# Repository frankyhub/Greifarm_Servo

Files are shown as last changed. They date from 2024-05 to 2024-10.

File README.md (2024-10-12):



<div align="center">

|[:skull:ISSUE](https://github.com/frankyhub/Greifarm_Servo/issues?q=is%3Aissue)|[:speech_balloon: Forum /Discussion](https://github.com/frankyhub/Greifarm_Servo/discussions)|[:grey_question:WiKi](https://github.com/frankyhub/Greifarm_Servo/wiki)||
|--|--|--|--|
| | | | |
||<a href="https://github.com/frankyhub/Greifarm_Servo/issues">|<a href="https://github.com/frankyhub/Greifarm_Servo/discussions">|<a href="https://github.com/frankyhub/Greifarm_Servo/releases">|
|| <a href="https://github.com/frankyhub/Greifarm_Servo/pulse" alt="Activity">| <a href="https://github.com/frankyhub/Greifarm_Servo/graphs/traffic">  |<a href="https://github.com/frankyhub?tab=stars"> |
</div>

# Greifarm mit Servo-Motore

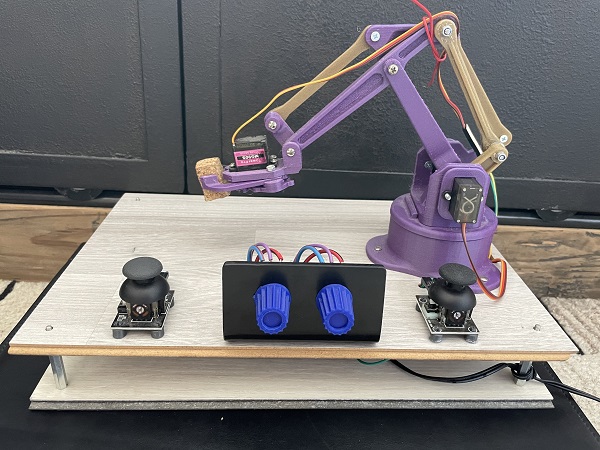
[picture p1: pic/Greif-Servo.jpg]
Bild


---

<div style="position:absolute; left:2cm; ">   
<ol class="breadcrumb" style="border-top: 2px solid black;border-bottom:2px solid black; height: 45px; width: 900px;"> <p align="center"><a href="#oben">nach oben</a></p></ol>
</div>  

---

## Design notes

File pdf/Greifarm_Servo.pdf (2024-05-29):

http://www.instructables.com/id/EEZYbotARM/technology (http://www.instructables.com/tag/type-id/category-technology/) workshop (http://www.instructables.com/tag/type-id/category-workshop/) craft (http://www.instructables.com/tag/type-id/category-craft/) home (http://www.instructables.com/tag/type-id/category-home/) food (http://www.instructables.com/tag/type-id/category-food/) play (http://www.instructables.com/tag/type-id/category-play/) outside (http://www.instructables.com/tag/type-id/category-outside/) costumes (http://www.instructables.com/tag/type-id/category-costumes/)

# EEZYbotARM

by theGHIZmo (http://www.instructables.com/member/theGHIZmo/?utm_source=pdf&utm_campaign=title) on September 29, 2015

Table of Contents

## Intro: EEZYbotARM

This ia a 3DPrinted robot arm.

The design intent was to make something "easy" to build and quite cheap

It uses MG90S small servos for driving the kinematics linkage and a Pololu mini maestro 12 to control the servos (but this is my choice any other methods are valid)

All the pieces are 3DPrinted in ABS but any other material like PLA can be used

3D models in stl format can be downloaded for free at Thingiverse : http://www.thingiverse.com/thing:1015238

video of :

ramp loop test :

https://youtu.be/qovZKW0DxWk

preliminary tests video :

https://www.youtube.com/watch?v=x9C_3WHr1G0

https://www.youtube.com/watch?v=0OFL6MxbPIM

Part list:

n° 17 3D printed parts

n* 3 Tower Pro MG90S servos

n* 1 SG90 servo (gripper) + 1 optional for the loop ramp

n° 7 M4 self locking nuts

n° 15 M4 washers

n° 7 M3 nuts

n° 1 M3 x 30 screw

n° 2 M3 washers

n° 4 M3 x 12 hex screw

n° 2 M3 x 12 TCEI screw

n° 2 M3 x 20 TCEI screw

n° 1 brass pipe 4 x 3 x 22 + n°1 4 x 3 x 26

ELECTRONICS

The Arm can be driven in several different ways : sketches, potentiometers, joystick, WII nunchuck …. after several trials I found very "easy" to use a controller from Pololu: Mini Maestro USB Servo Controller. You can attach up to 6 – 12 – 24 servos depend of the controller type. It is provided with a free configuration and control program for Windows and Linux that give you the power to drive the servo in manual moving slides; in the mean time you are able to set the values of speed and acceleration for any singular item. You can also build sequences of servo movements and run scripts stored in the internal script memory that can be automatically played back without any computer or external microcontroller connected.

here the link of the Pololu servo controller: https://www.pololu.com/product/1352

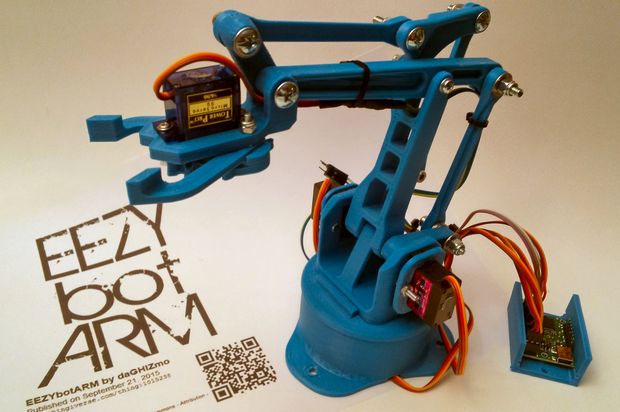
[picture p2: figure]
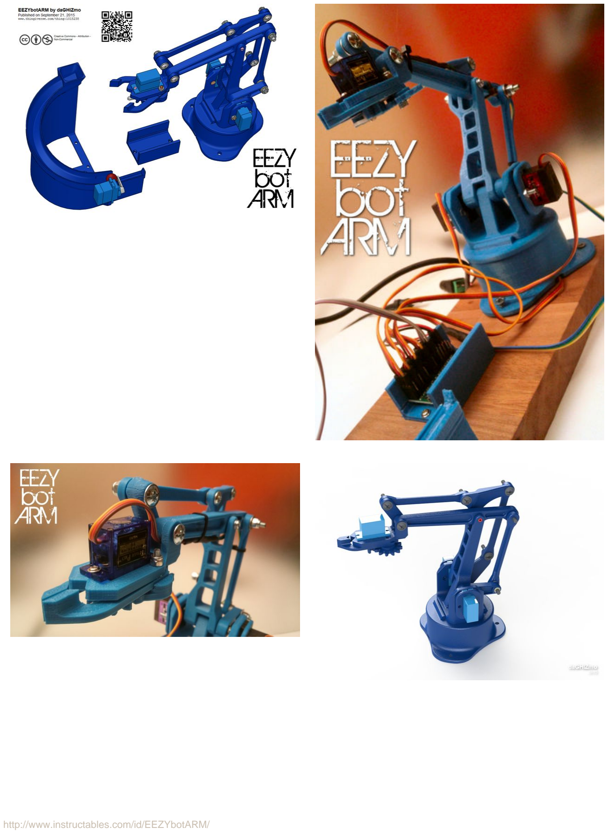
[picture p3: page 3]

## Step 1:

Connect two link arms (003) to the Triangular link (006).

Keep the M4 round heads screws to the inner side like shown on image and selflocking nuts to the outer side.

IMPORTANT

I design all the holes of joints quite exact to allow to make them more precise using a drill bit

The nuts are to be tightened till the locking of the joint, then consequently you must loose them until you obtain a smooth movement with the lower clearance between components. This rule is valid and is to be applied also for the following joint that involve use of self locking nuts.

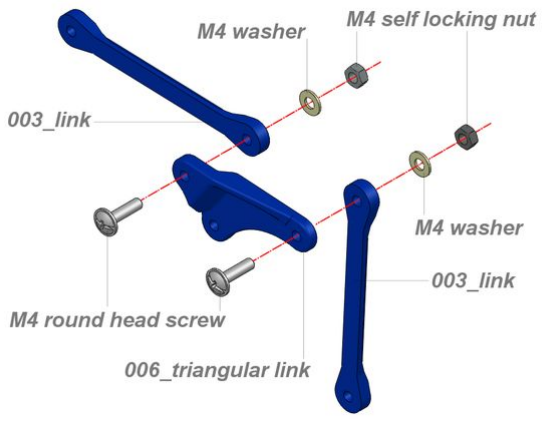
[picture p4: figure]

## Step 2:

Connect link (003) to the rear joint of the horizontal arm (005).

The lower part of the link (003) is to be connected with the vertical drive arm (002) as shown.

Between the two links interpose three M4 washer, this to better align them with the vertical arm

Keep the M4 round heads screws to the inner side and self locking nuts outside

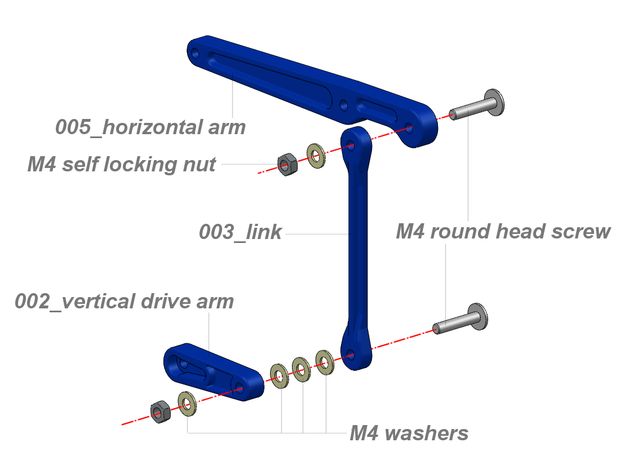
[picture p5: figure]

## Step 3:

Connect now the two preassembled links to the main arm (004).

Punt in position horizontal arm () and triangular link () aligned with the upper connection of the main arm (). Insert the Ø4 mm brass pipe crossing all the parts and fix it with the M3x30 screw, locked by the nut on the other side.

Verify the freedom of movement and If everything is ok, proceed to the next step.

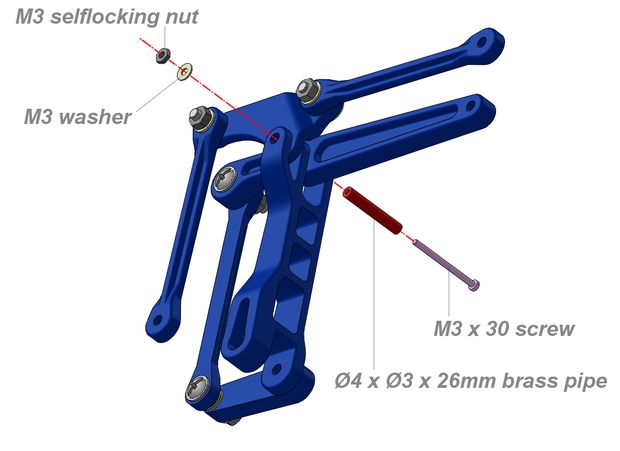
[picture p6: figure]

## Step 4: Base assembly

Part list:

- n° 1 EBA_01.00.001_base.stl
- n° 1 EBA_01.00.011_round plate.stl
- n° 1 EBA_01.00.010_basement.stl
- n° 1 TowerPro metal gear MG90S servo with double arm horn
- n° 1 servo horn fixing screw
- n° 2 M3 x 15 screw (VTCEI)
- n° 3 M3 nuts

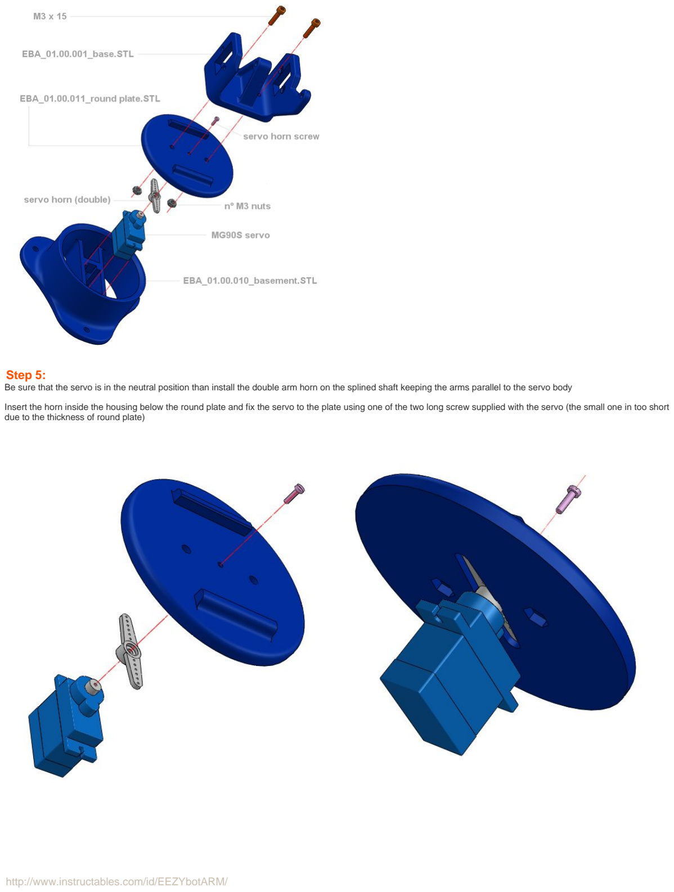
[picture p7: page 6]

## Step 5:

Be sure that the servo is in the neutral position than install the double arm horn on the splined shaft keeping the arms parallel to the servo body

Insert the horn inside the housing below the round plate and fix the servo to the plate using one of the two long screw supplied with the servo (the small one in too short due to the thickness of round plate)

## Step 6:

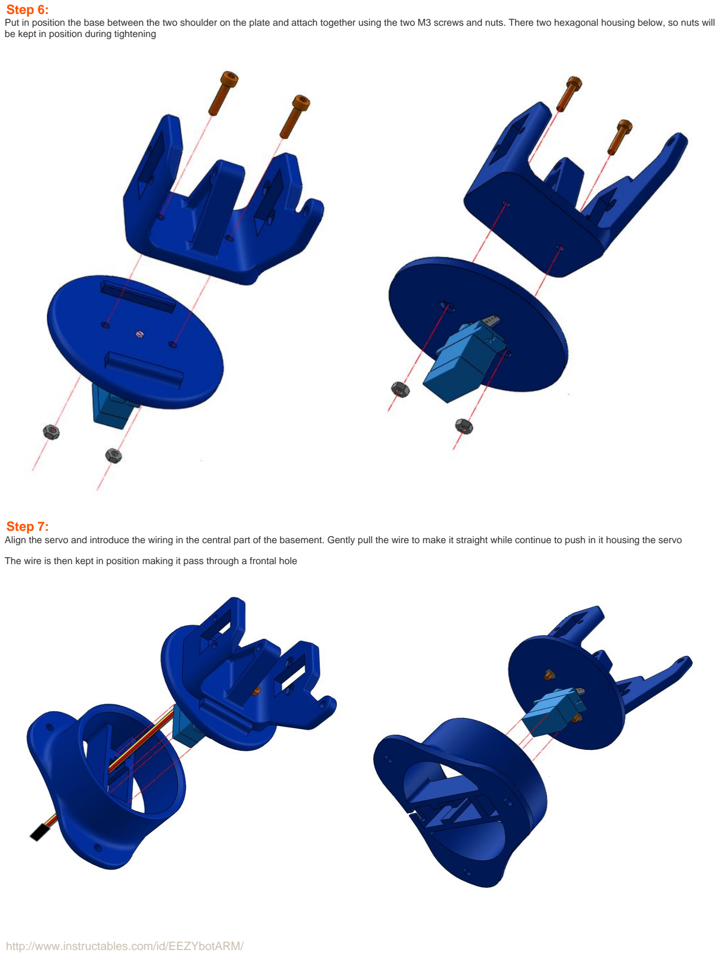
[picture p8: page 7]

Put in position the base between the two shoulder on the plate and attach together using the two M3 screws and nuts. There two hexagonal housing below, so nuts will be kept in position during tightening

## Step 7:

Align the servo and introduce the wiring in the central part of the basement. Gently pull the wire to make it straight while continue to push in it housing the servo

The wire is then kept in position making it pass through a frontal hole

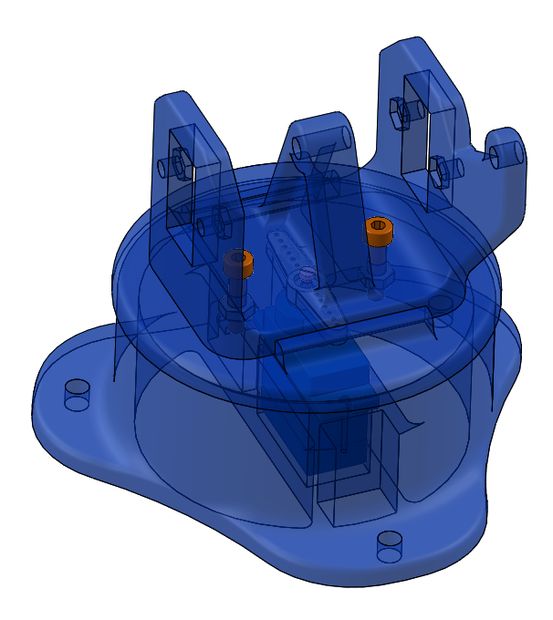
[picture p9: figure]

## Step 8: Gripper assembly

Part list:

- n° 1 TowerPro metal gear MG90S servo with single arm horn
- n° 1 servo horn fixing screw
- n° 1 EBA_01.00.012_claw support.stl
- n° 1 EBA_01.00.015_drive gear.stl
- n° 1 EBA_01.00.014_left finger.stl
- n° 1 EBA_01.00.016_driven gear.stl
- n° 1 EBA_01.00.013_right finger.stl
- n° 2 M3 x 20 screw (TCEI)
- n° 3 M3 selflocking nuts

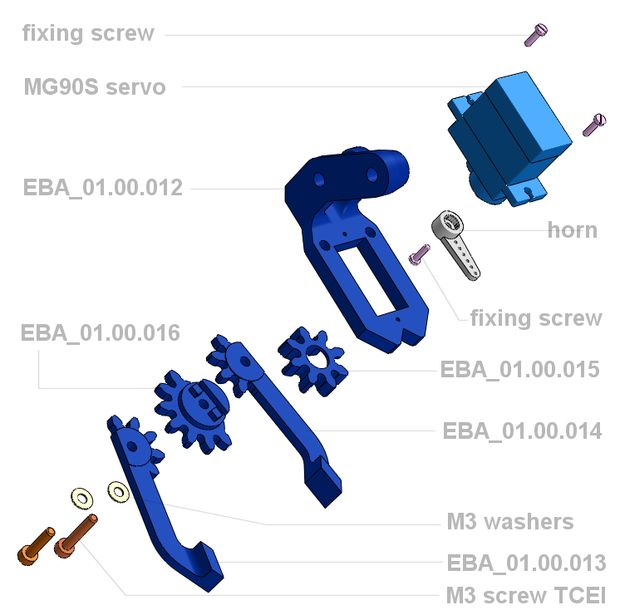
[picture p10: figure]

## Step 9:

Attach the servo to the claw support using the two fixing screws supplied with the servo

Keep the output shaft forward

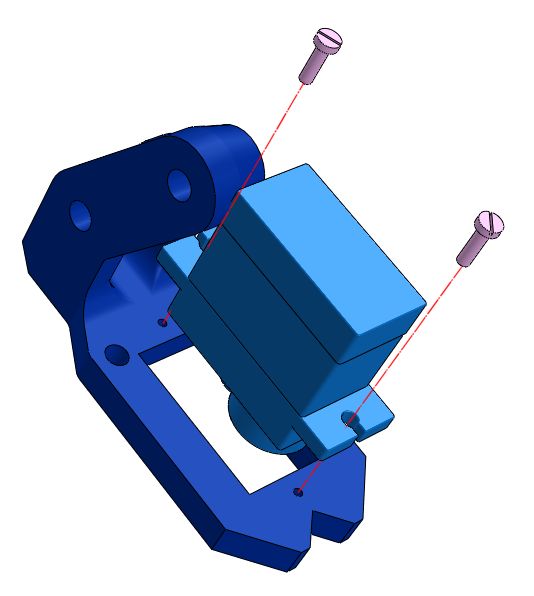
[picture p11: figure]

## Step 10:

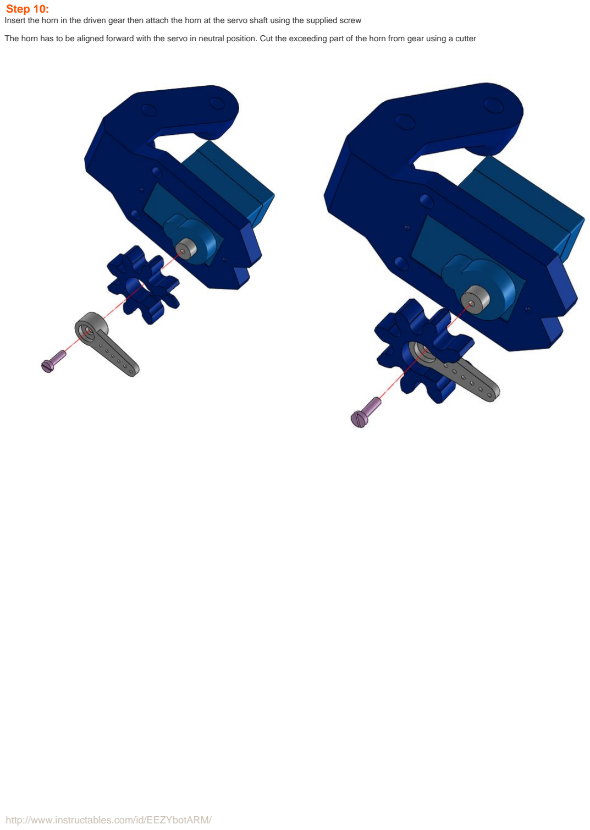
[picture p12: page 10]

Insert the horn in the driven gear then attach the horn at the servo shaft using the supplied screw

The horn has to be aligned forward with the servo in neutral position. Cut the exceeding part of the horn from gear using a cutter

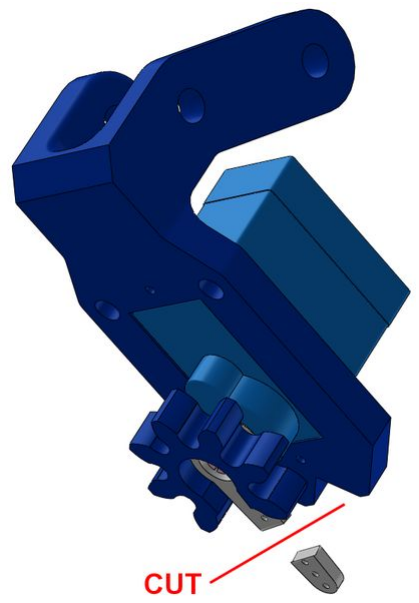
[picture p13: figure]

## Step 11:

Insert an M3 screw in the central hole connect it to the claw support then tight the self locking nut checking the freedom of movement

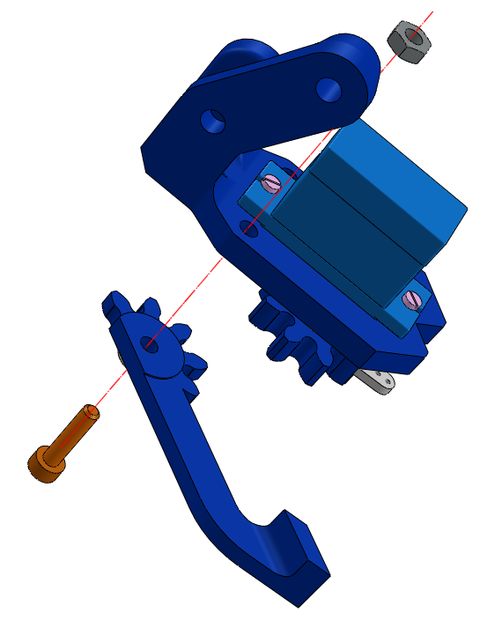
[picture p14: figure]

## Step 12:

Insert the two pin of the driven gear into the dedicated holes on the left finger The driven gear has also a shoulder that has to be aligned with the lateral side of the finger. If you find difficulties coupling them, reduce interference using a file.

Once coupled insert an M3 screw in the central hole and attach the finger to the claw support

Now the gripper is ready to be installed on the horizontal arm of the EEzybot

Verify freedom of movement of the gripper manually or using a servo tester

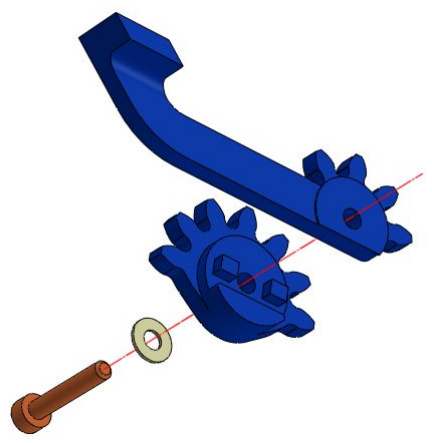
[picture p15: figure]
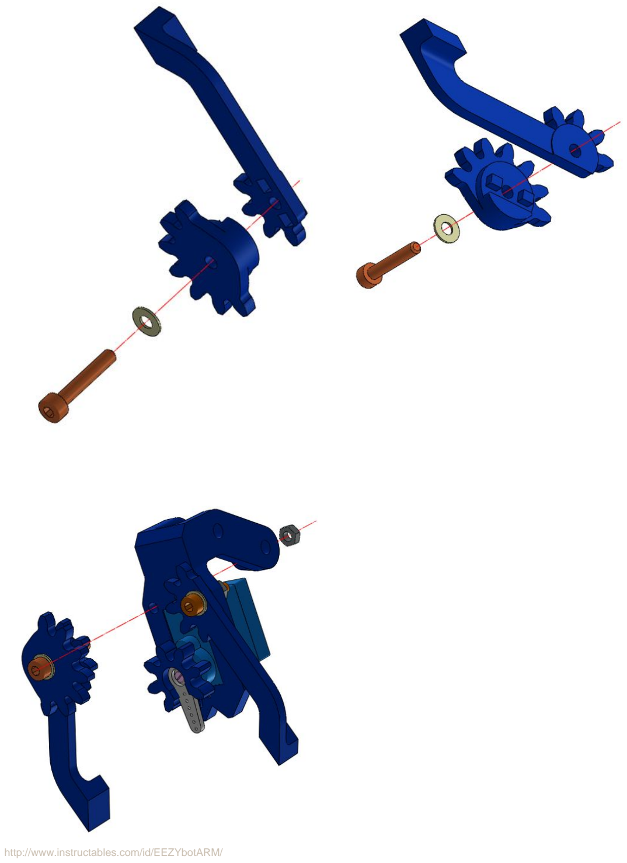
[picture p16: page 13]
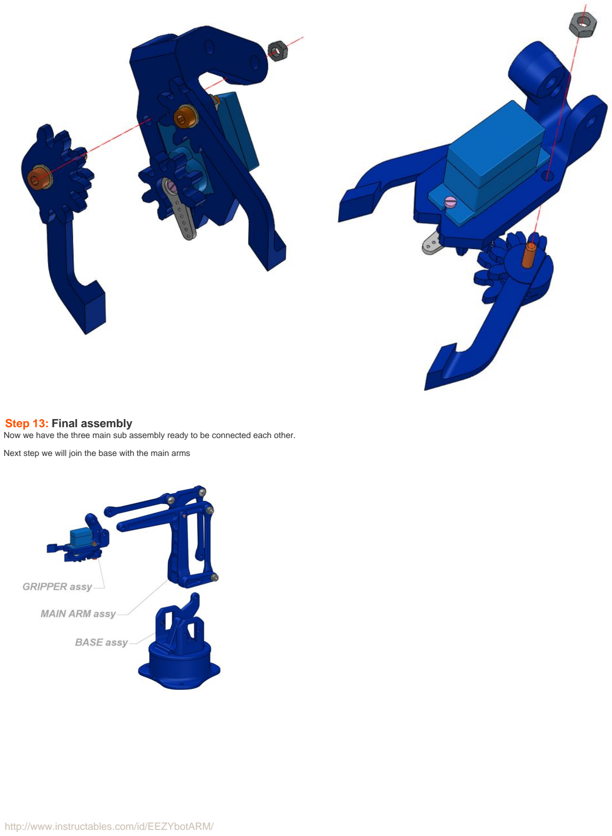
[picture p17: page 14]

## Step 13: Final assembly

Now we have the three main sub assembly ready to be connected each other.

Next step we will join the base with the main arms

## Step 14:

To join the base with the main arms align the axis of the parts and insert from one side the brass pipe 24mm long.

Also the short arm of the servo that drive the vertical movement has to be supported by the brass pipe as shown on the pictures.

Check the freedom of movement

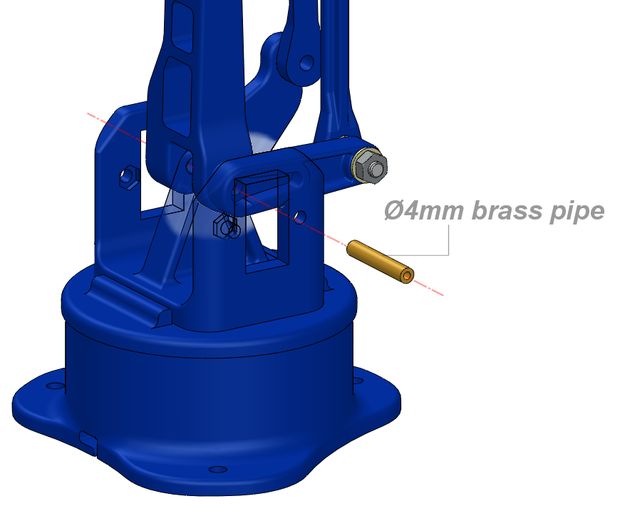
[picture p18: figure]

## Step 15:

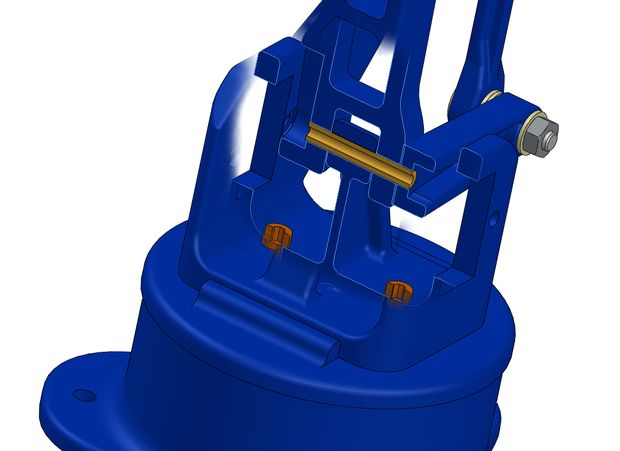
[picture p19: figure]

Is time now to install the servo that drive the vertical movement of the arm. Put in the dedicate receptacles two M3x10 hex screw. The servo has to be in the neutral position with the horn at 90 degrees on the right side with the press plate (009) installed (Make the wiring pass through the dedicated enlargment).

Introduce the servo angled in the square seat on the base plate and slide the horn in the shaped housing of the arm that drives the vertical movement. Fixt the press plate against the servo using two M3 nuts

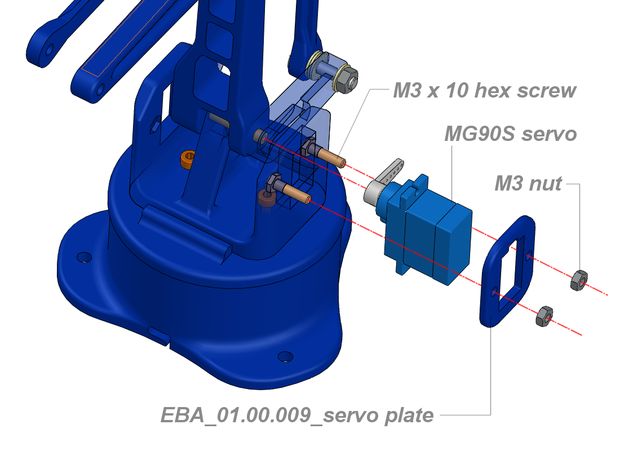
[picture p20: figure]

## Step 16: Fwd/bckw drive servo

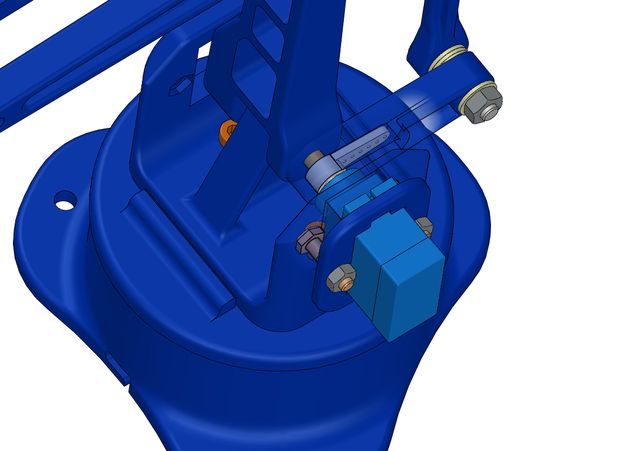
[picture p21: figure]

Sequence for the forward&backward driving servo is similar to the previous. In this case the servo horn has to be installed with the servo in neutral condition aligned vertically.

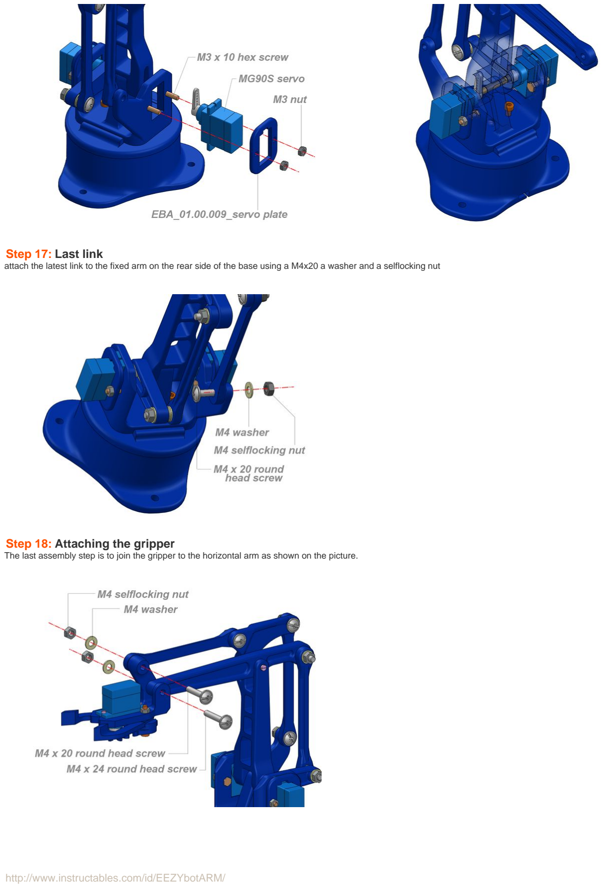
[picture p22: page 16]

## Step 17: Last link

attach the latest link to the fixed arm on the rear side of the base using a M4x20 a washer and a selflocking nut

## Step 18: Attaching the gripper

The last assembly step is to join the gripper to the horizontal arm as shown on the picture.

## Step 19: Making it work

At the end of the last step the ARM is ready to work.

As an optional, In the 3D model downodable from Thinghiverse, I add a round ramp that allow to easy obtain a loop test with a ball (3D printed, obviously!). In the video linked on first page is shown what I mean.

To make this tool to work you have to attach another servo (cheap SG90) to the end of the ramp. I keep th ramp center at a distance of about 180mm from the base vertical axis.

There is also a 3D model of a support dedicated to the Pololu USB servo.

The way to drive the servo are several. I tried them pretty all. To explain it will take to much and this instructable is big enough ..... probably I'll make a new instructables dedicated, If I get time. Anyway if you want to explore there are quite enough material around the web.

As told at the beginning, I found very easy using a Pololu USB servo Mini Maestro, it is not very cheap but solve a lot of problems. You have to install drivers, a software and when connected to usb you're are immediately able to drive the servos choosing their speed and acceleration also. You can store the servo position to a sequence and when ready it can be played once or in a loop. Can also be stored in the internal script memory and it can be automatically played without computer connected.

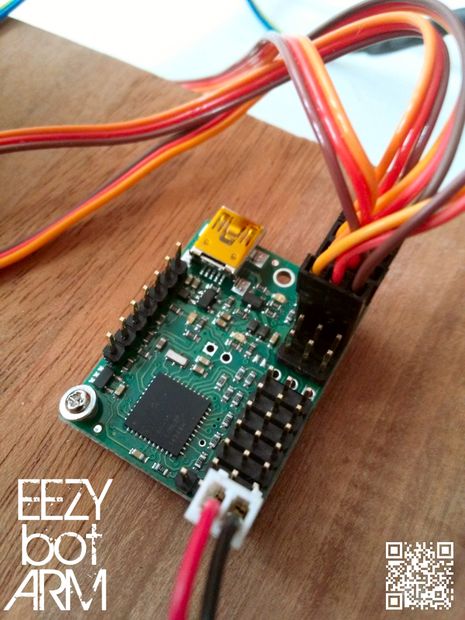
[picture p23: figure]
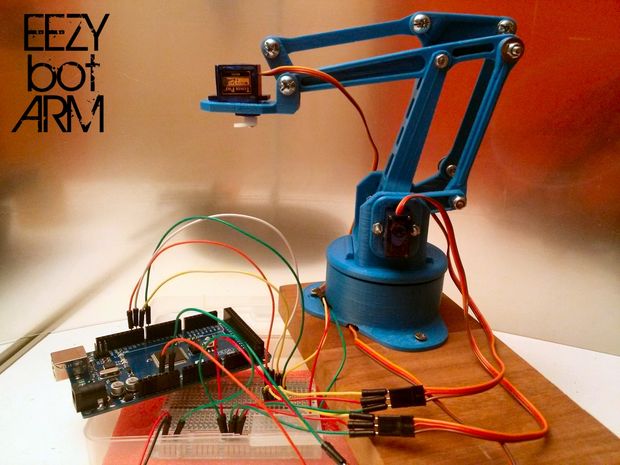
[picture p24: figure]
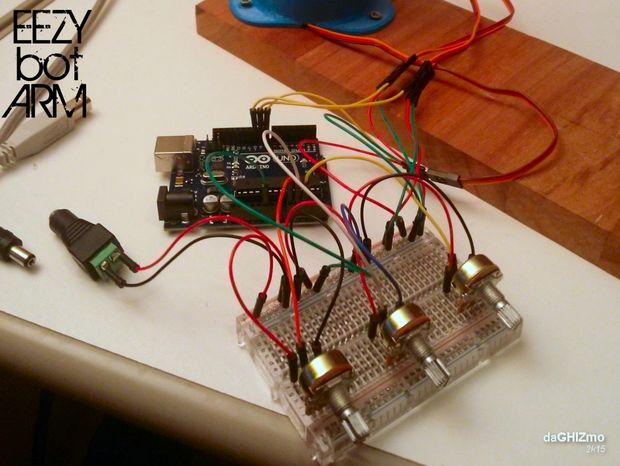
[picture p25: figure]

## Related Instructables

Robot (Part 1.0) (http://www.instructables.com/id/Biped-Fighting-Robot-Part-10/?utm_source=pdf&utm_campaign=related)
by 159753 (http://www.instructables.com/member/159753/?utm_source=pdf&utm_campaign=related)

"Can" Bot (http://www.instructables.com/id/Can-Bot/?utm_source=pdf&utm_campaign=related) by
ywj_pheej (http://www.instructables.com/member/ywj_pheej/?utm_source=pdf&utm_campaign=related)

3D Printed
Robot ARM (http://www.instructables.com/id/Make-your-own-3D-Printed-Robot-ARM/) by
roboteurs (http://www.instructables.com/member/roboteurs/?utm_source=pdf&utm_campaign=related)

Rock - Paper -
Scissors Robot
from Lego
Mindstorms
NXT! (http://www.instructables.com/id/Self-Learning-Rock-Paper-Scissors-Robot-from-L/) by
prrgg14935 (http://www.instructables.com/member/prrgg14935/?utm_source=pdf&utm_campaign=related)

Arm (http://www.instructables.com/id/Three-Fingered-Arduino-Robotic-Arm/) by
prototypeBOTs (http://www.instructables.com/member/prototypeBOTs/?utm_source=pdf&utm_campaign=related)

Making a
Robotic Arm
with Chainsaw
& Sawzall Axe
(video) (http://www.instructables.com/id/Sculpture-Robot-Part-5-of-9-Making-a-Robotic-Arm-w/) by
morganrauscher (http://www.instructables.com/member/morganrauscher/?utm_source=pdf&utm_campaign=related)

Advertisements

## Comments

1 comments | Add Comment (http://www.instructables.com/id/EEZYbotARM/?utm_source=pdf&utm_campaign=comments#comments)
DIY Hacks and How Tos (http://www.instructables.com/member/DIY+Hacks+and+How+Tos/?utm_source=pdf&utm_campaign=comments) says: | Oct 4, 2015. 8:32 PM REPLY (http://www.instructables.com/id/EEZYbotARM/?utm_source=pdf&utm_campaign=comments#DISCUSS)
Nice robot arm design.

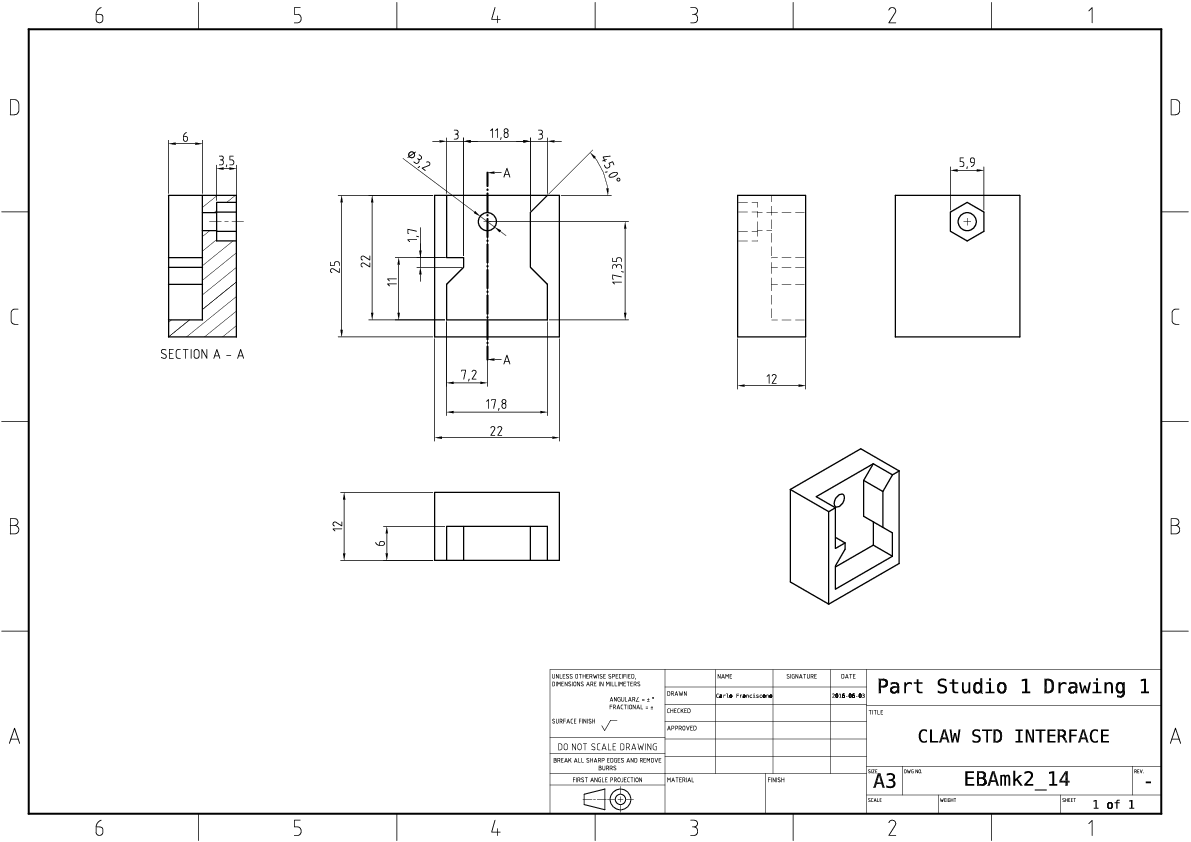
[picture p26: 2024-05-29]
pic/MK_2_3.png

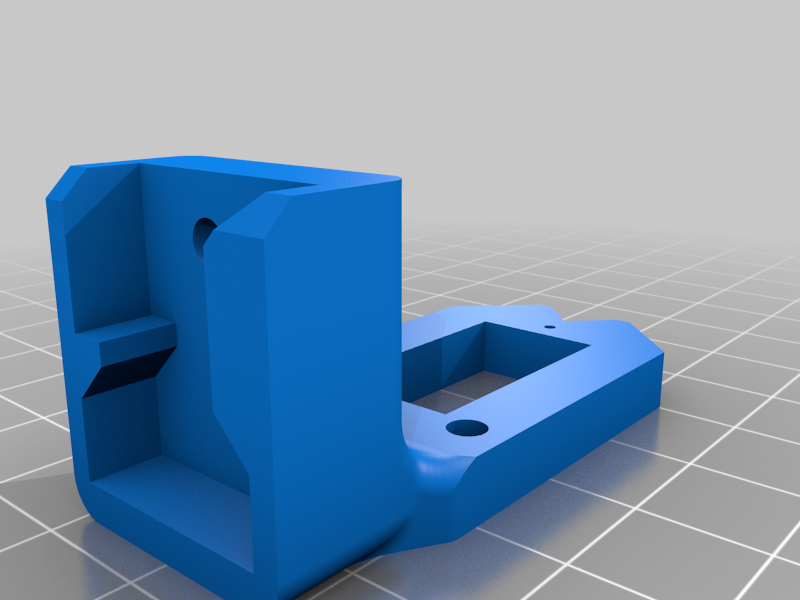
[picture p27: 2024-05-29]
pic/MK_2_18.png

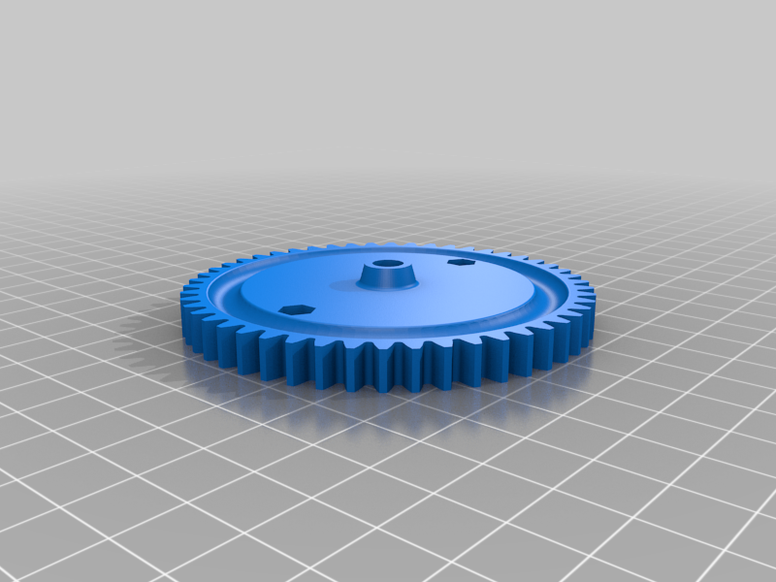
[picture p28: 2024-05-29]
pic/MK_2_1.png

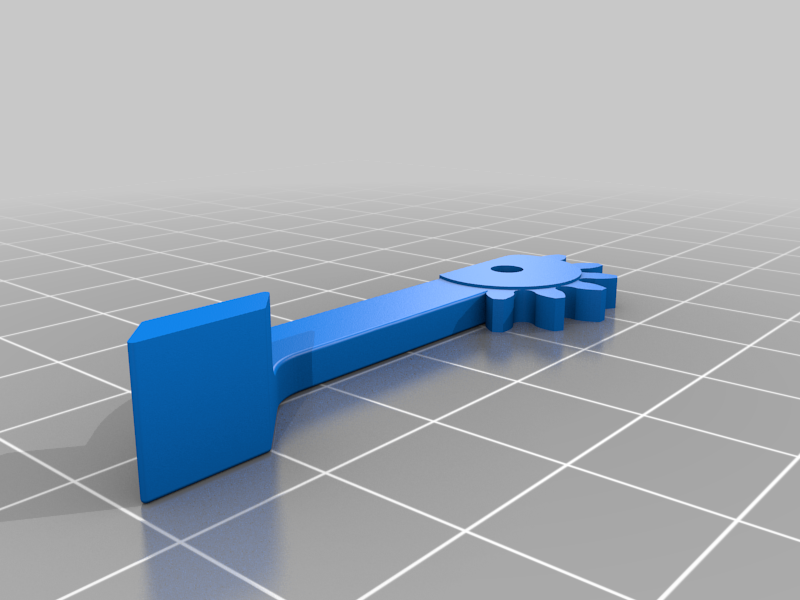
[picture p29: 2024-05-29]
pic/MK_2_19.png

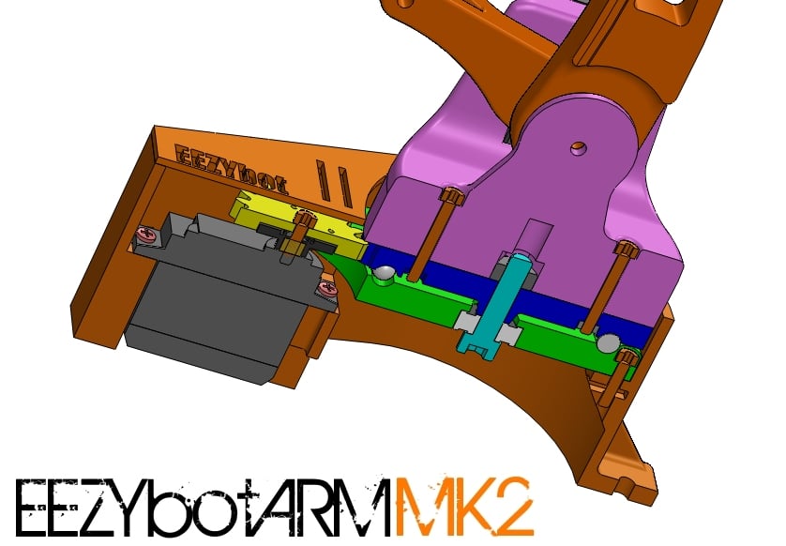
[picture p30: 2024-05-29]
pic/Ebamk2_cut_01.jpg

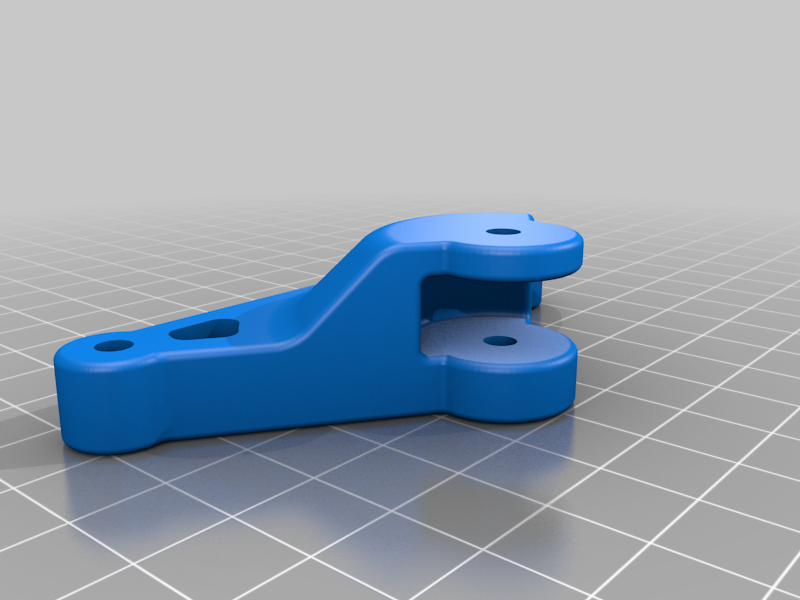
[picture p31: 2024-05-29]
pic/MK_2_15.png

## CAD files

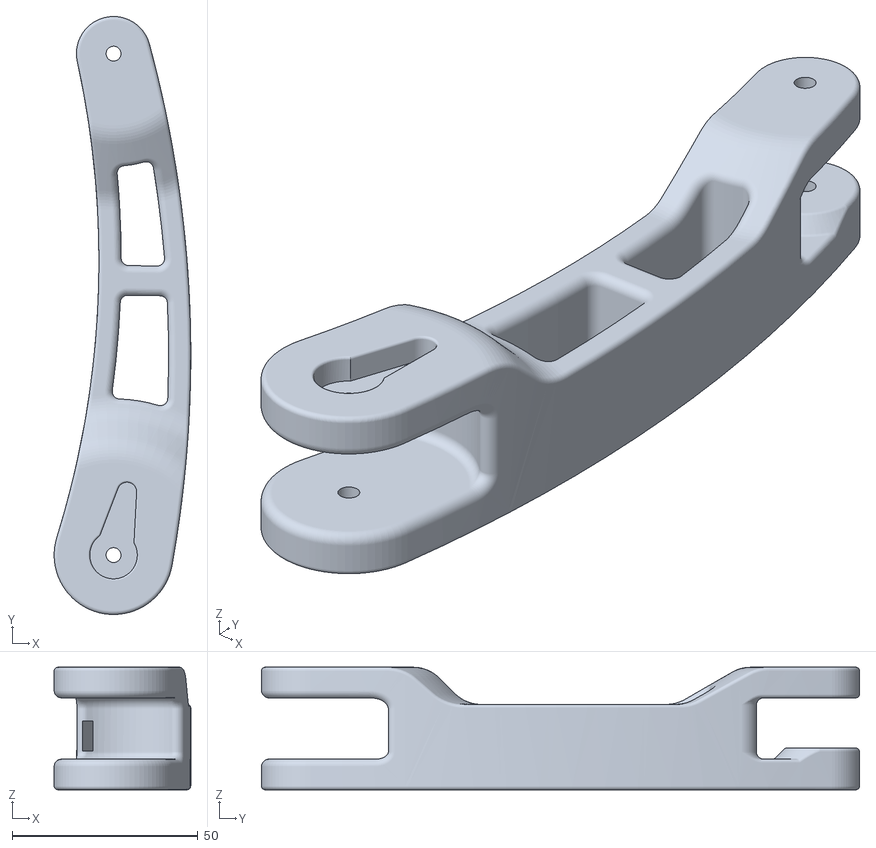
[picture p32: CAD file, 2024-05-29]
stl/EBAmk2_002_mainarm.STL
36.8 x 161.0 x 33.0

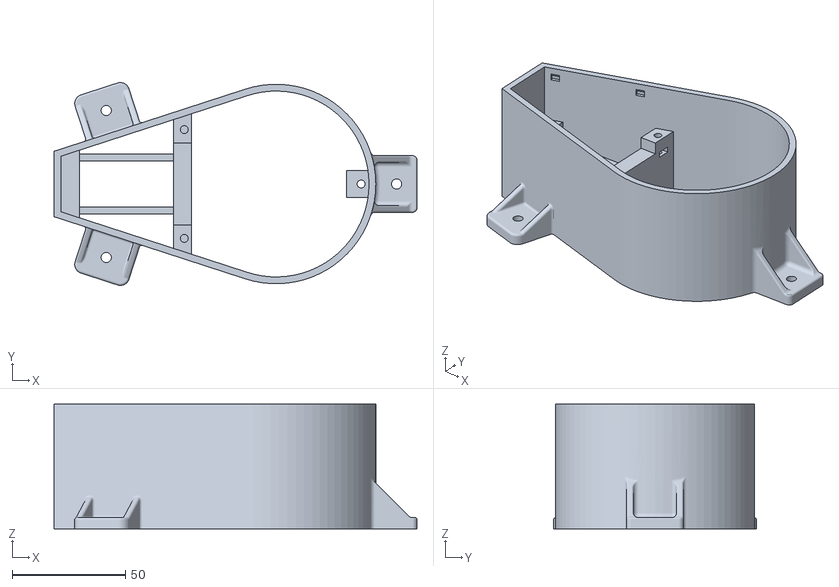
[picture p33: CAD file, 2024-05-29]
stl/EBAmk2_012_mainbase.STL
160.2 x 89.5 x 55.0

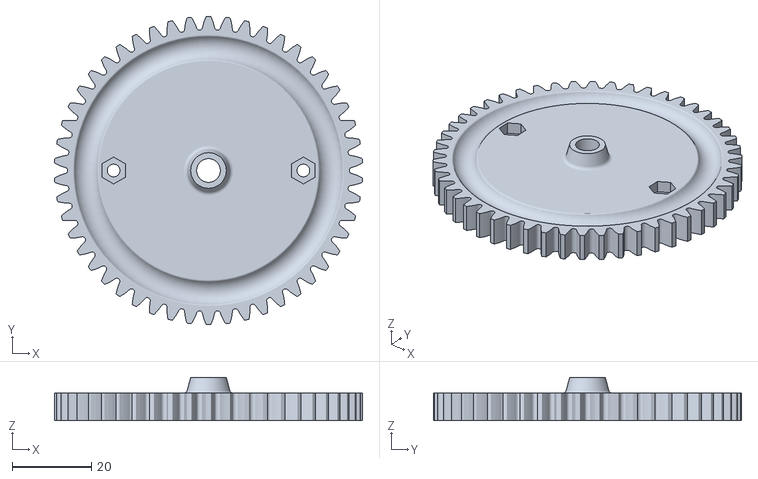
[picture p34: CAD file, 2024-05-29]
stl/EBAmk2_011_gearmast_full.STL
77.9 x 78.0 x 11.0

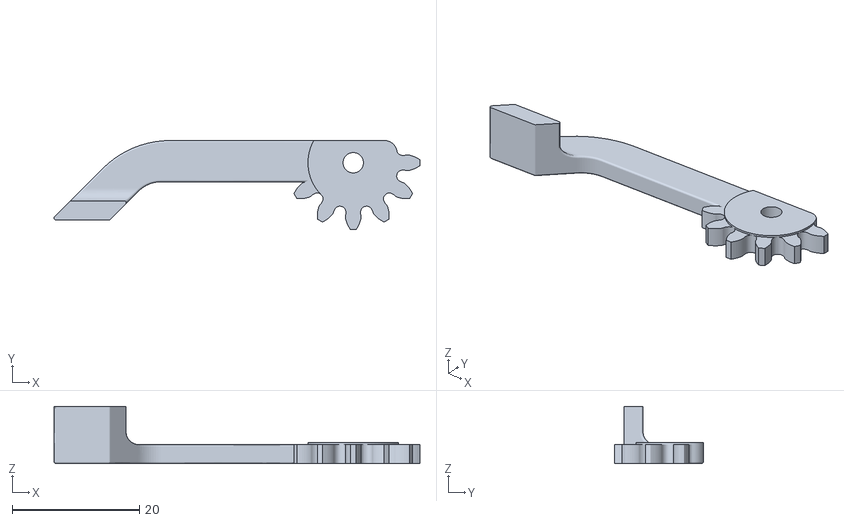
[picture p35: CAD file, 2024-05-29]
stl/EBAmk2_015_claw_finger_dx.STL
57.6 x 14.0 x 9.00

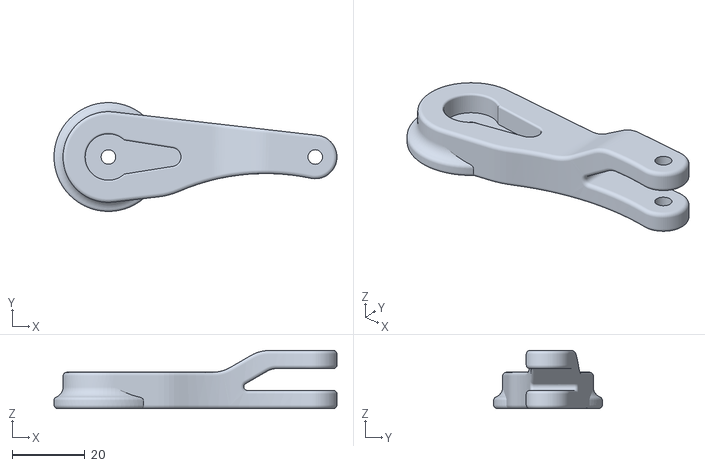
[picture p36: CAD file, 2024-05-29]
stl/EBAmk2_003_varm.STL
78.0 x 30.0 x 16.0

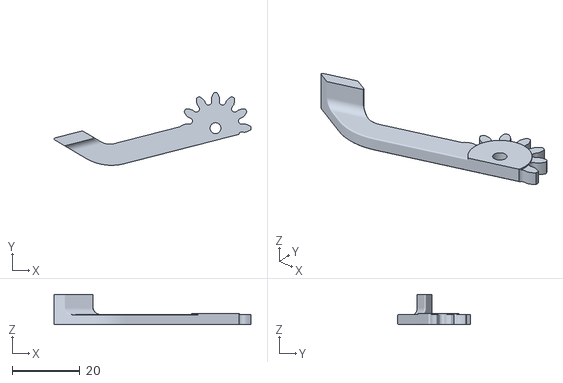
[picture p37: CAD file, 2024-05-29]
stl/EBAmk2_017_claw_finger_sx.STL
58.3 x 21.5 x 9.00

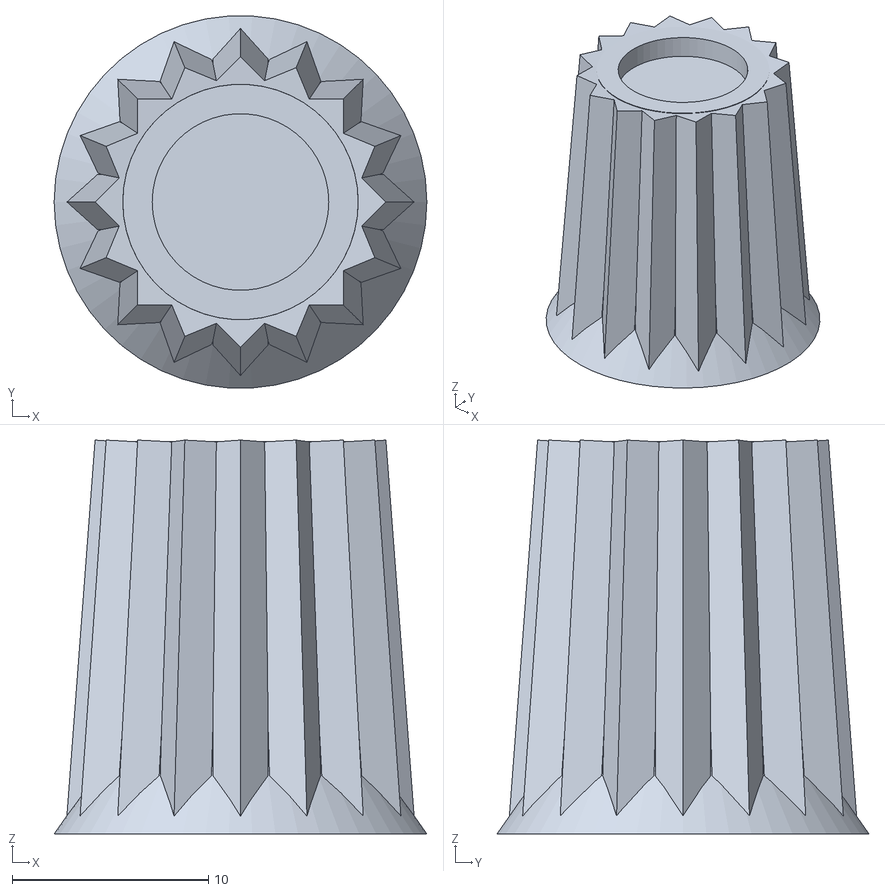
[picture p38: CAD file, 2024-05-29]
stl/Drehknopf.stl
19.0 x 19.0 x 20.1

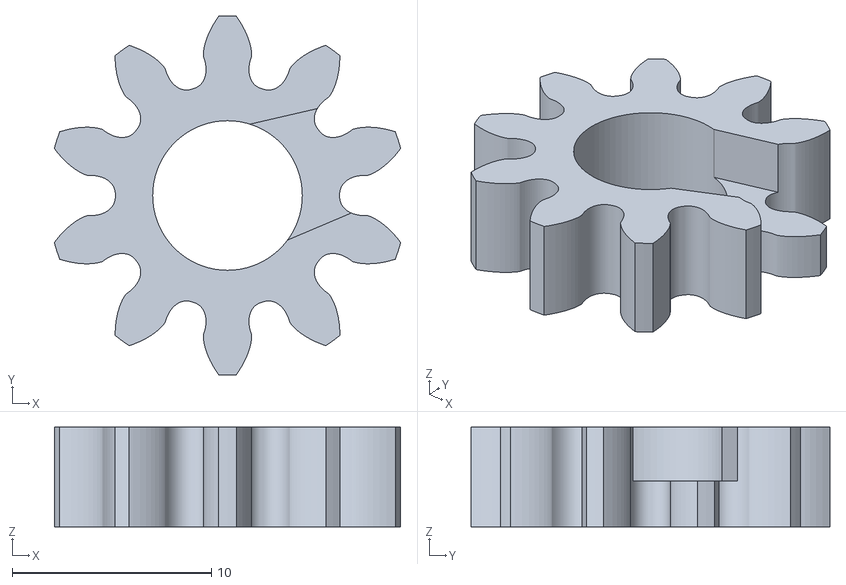
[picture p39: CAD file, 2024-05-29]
stl/EBAmk2_016_claw_gear_drive.STL
17.4 x 18.0 x 5.00

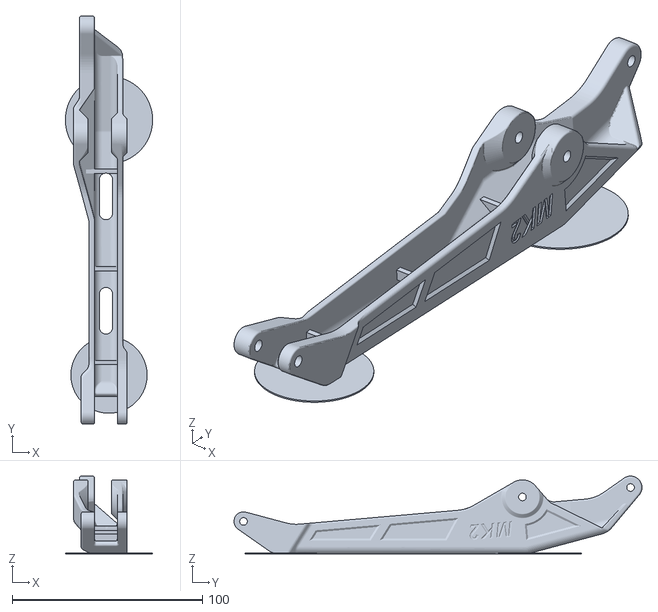
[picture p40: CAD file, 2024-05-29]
stl/EBAmk2_006_horarm_plate.STL
45.8 x 214.2 x 40.9

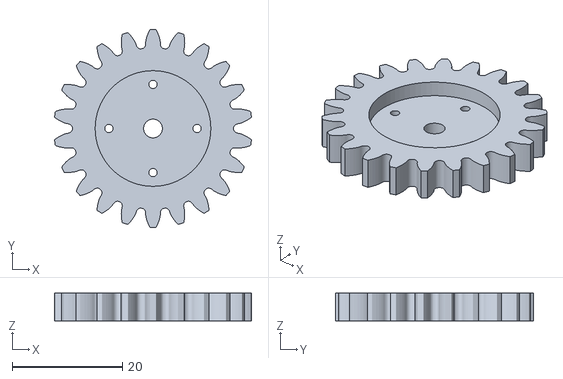
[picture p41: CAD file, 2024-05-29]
stl/EBAmk2_010_gearservo_22DENTI.STL
35.8 x 36.0 x 5.00

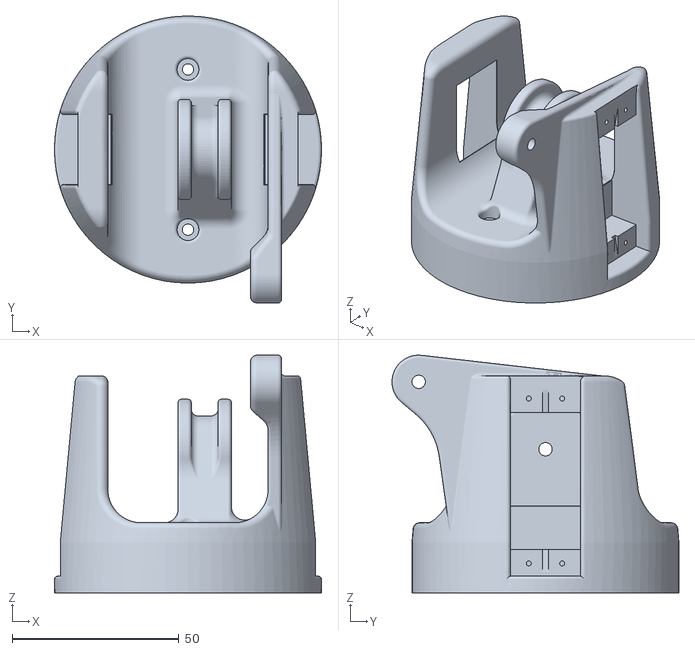
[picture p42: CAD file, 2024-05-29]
stl/EBAmk2_001_base.STL
80.0 x 86.0 x 71.2

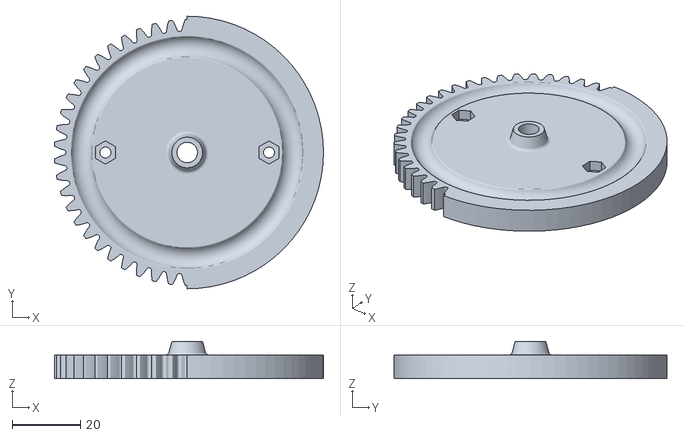
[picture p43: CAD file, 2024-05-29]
stl/EBAmk2_011_gearmast.STL
79.0 x 80.0 x 11.0

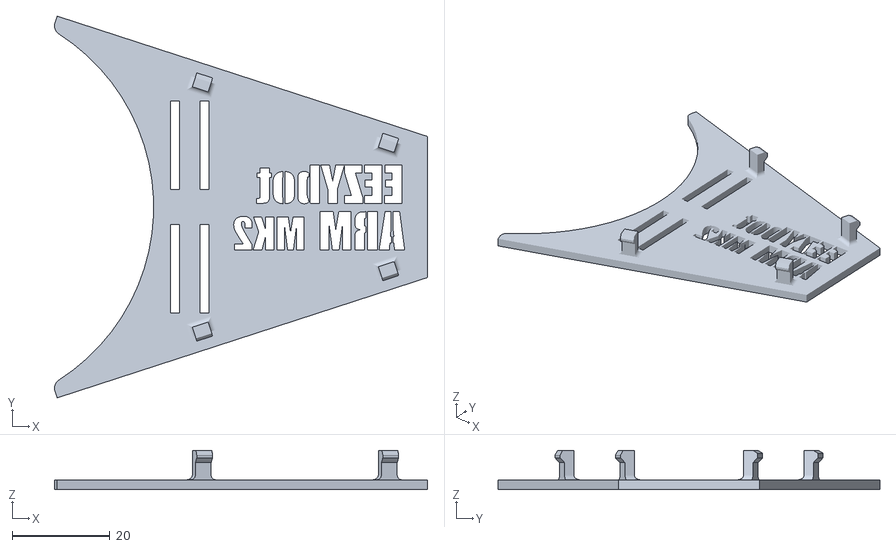
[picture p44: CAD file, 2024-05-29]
stl/EBAmk2_019_drive_cover.STL
76.3 x 78.1 x 8.00

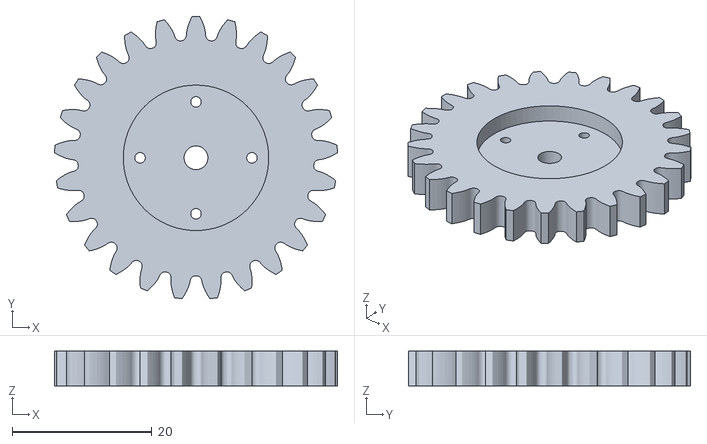
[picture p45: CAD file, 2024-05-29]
stl/EBAmk2_010_gearservo.STL
40.5 x 40.4 x 5.00

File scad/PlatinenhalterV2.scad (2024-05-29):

$fn=130;

zylD=6.6;   //Zylinder-Durchmesser
zylH=10;    //Zylinder-Höhe
pinD=3;     //PIN-Durchmesser
pintack(h=6);//Pin-Höhe


module pin(h=10, r=4, lh=3, lt=1) { 
    pin_vertical(h, r, lh, lt);
}

module pintack(h=10, r=pinD, lh=3, lt=1,) {
   union() {
    cylinder(h=zylH, r=zylD);
    translate([0, 0, zylH]) pin(h, r, lh, lt);
  }
}

module pin_vertical(h=10, r=4, lh=3, lt=1) {

  difference() {
    pin_solid(h, r, lh, lt);
    translate([-r*0.5/2, -(r*2+lt*2)/2, h/4]) cube([r*0.5, r*2+lt*2, h]);
    translate([0, 0, h/4]) cylinder(h=h+lh, r=r/2.5, $fn=20);
    translate([-r*2, -lt-r*1.125, -1]) cube([r*4, lt*2, h+2]);
    translate([-r*2, -lt+r*1.125, -1]) cube([r*4, lt*2, h+2]);
  }
}

module pin_solid(h=10, r=4, lh=3, lt=1) {
  union() {

    cylinder(h=h-lh, r=r, $fn=30);
    translate([0, 0, h-lh]) cylinder(h=lh*0.25, r1=r, r2=r+(lt/2), $fn=30);
    translate([0, 0, h-lh+lh*0.25]) cylinder(h=lh*0.25, r=r+(lt/2), $fn=30);    
    translate([0, 0, h-lh+lh*0.50]) cylinder(h=lh*0.50, r1=r+(lt/2), r2=r-(lt/2), $fn=30);    
  }
}

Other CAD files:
stl/EBAmk2_004_link135.STL
stl/EBAmk2_013_lower_base.STL
stl/EBAmk2_014_claw_base.STL
stl/EBAmk2_014_claw_std.step
scad/Drehknopf.scad
stl/EBAmk2_005_link135angled.STL
stl/EBAmk2_006_horarm__.STL
stl/EBAmk2_007_trialink.STL
stl/EBAmk2_008_link147_new.STL
stl/EBAmk2_009_trialinkfront.STL
stl/EBAmk2_014_claw_std.dwg
stl/EBAmk2_018_claw_gear_driven.STL

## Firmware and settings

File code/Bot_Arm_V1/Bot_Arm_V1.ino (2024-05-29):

/* Roboterarm Servo Ansteuerung
 *  Board NANO
 *  ATmega328P
 *  LIB: VarSpeedServo.h
 *  https://github.com/netlabtoolkit/varspeedservo
 *  
 *  V1
 *  18-10-2020 KHF
 */


#include <VarSpeedServo.h> 


VarSpeedServo Gr_servo; //Greifarm
VarSpeedServo Dr_servo; //Drehteller
VarSpeedServo Ki_servo; //Kippen
VarSpeedServo He_servo; //Heben

int Poti_Greifen = A1;    //Greifarm
int Poti_Drehen = A2;     //Drehteller
int Joystick_Kippen = A3; //Kipp
int Joystick_Heben = A4;  //Heben

int Greifarm;
int Drehteller;
int Kippen;
int Heben;

//Speed festlegen:
int SPEED = 30; //30 bei Test


void setup() {
  Gr_servo.attach(6);   //PWM#6
  Dr_servo.attach(9);   //PWM#9
  Ki_servo.attach(10);  //PWM#10
  He_servo.attach(11);  //PWM#11
} 
 
void loop() {

int Poti_Greifen = analogRead(A1);
int Poti_Drehen = analogRead(A2);
int Joystick_Kippen = analogRead(A3);
int Joystick_Heben = analogRead(A4);

  //Greifarm
  Greifarm = map(Poti_Greifen, 0, 1023, 0, 175);
  Gr_servo.write(Greifarm, SPEED);

//Drehteller
Drehteller = map(Poti_Drehen, 0, 1023, 0, 175);
Dr_servo.write(Drehteller, SPEED);

  //Kippen
  Kippen = map(Joystick_Kippen, 0, 1023, 0, 175);
  Ki_servo.write(Kippen, SPEED);

//Heben
Heben = map(Joystick_Heben, 0, 1023, 0, 150);
He_servo.write(Heben, SPEED);

    delay(100);
}
